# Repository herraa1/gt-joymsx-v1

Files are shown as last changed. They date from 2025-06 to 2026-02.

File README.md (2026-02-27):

# MSX Joystick to Gigatron TTL microcomputer Joystick adapter (gt-joymsx) v1

Connect [MSX Joysticks](https://www.msx.org/wiki/Joystick/joypad_controller) to the [Gigatron TTL microcomputer](https://gigatron.io/).

> [!NOTE]
>
> No build instructions are yet provided, but if you are brave enough go for the [recommended build](#recommended-build).
>

## Introduction

The gt-joymsx v1 is an adapter that allows connecting MSX joysticks to the Gigatron TTL microcomputer.

The main features of the gt-joymsx v1 adapter are:
* small footprint
* made of widely available electronic components
* behaves as a cord extension between the Gigatron TTL microcomputer and the MSX joystick
* uses an extension cable with a female DE9 connector on the adapter's Gigatron TTL microcomputer joystick side
* uses a male DE9 PCB connector on the adapter's MSX joystick side
* no need for external power supply, the adapter draws current from the Gigatron TTL microcomputer joystick port
* super low power consumption

## [Hardware](hardware/kicad/)

The Gigatron TTL microcomputer uses [9-pin Famiclone compatible joysticks](https://www.nesdev.org/wiki/Controller_port_pinout). Those joysticks use a [Texas Instruments 4021 or compatible](https://www.ti.com/lit/ds/symlink/cd4021b.pdf) to latch and serialize the information about the pressed joystick buttons and arrows.

The [standard MSX joysticks](https://www.msx.org/wiki/Joystick/joypad_controller) are completely passive and have parallel signals for each of the buttons and arrows. The MSX computers pull up by default the signals when a MSX joystick is connected, and the MSX joysticks pull the signals to the OUT signal (pin8) when buttons or arrows are pressed (see page 27 of [MSX Technical Data Book](https://map.grauw.nl/resources/system/msxtech.pdf) for a schematic).

The gt-joymsx v1 adapter uses a CD4021BM integrated circuit to convert the signals from the MSX joystick buttons and arrows to the 9-pin Famiclone expected signalling.
As the MSX joysticks lack the `SELECT` and `START`buttons of the Famiclone joysticks, the gt-joymsx v1 adapter itself also provides two Cherry-compatible key switches to add those two buttons.

A two-sided printed circuit board (PCB) is used to put together all components:
* An angled Sega DE9 PCB male connector is used to directly connect the MSX joystick
* A PH2.0 connector is used to connect the Gigatron TTL microcomputer joystick cable extension
* Two Cherry-compatible key switches to implement the `SELECT` and `START` buttons
* the CD4021BM CMOS 8-Stage Static Shift Register
* A pair of pull-up resistor networks to provide default signals for buttons and arrows

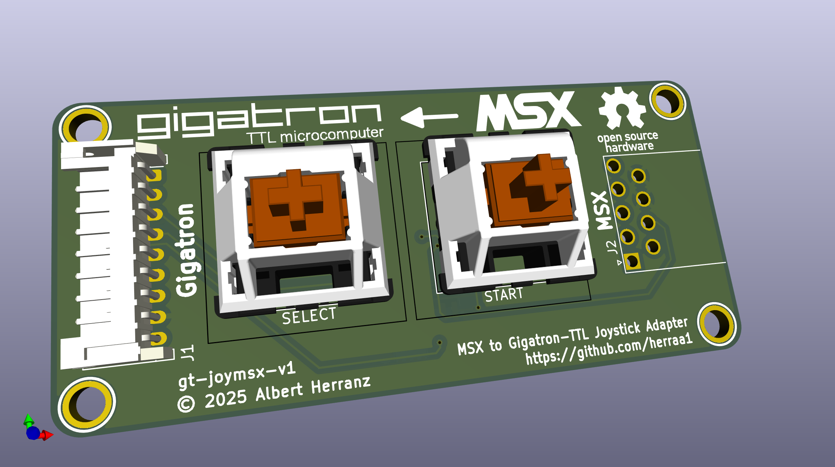
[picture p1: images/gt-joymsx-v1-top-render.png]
[](images/gt-joymsx-v1-top-render.png)

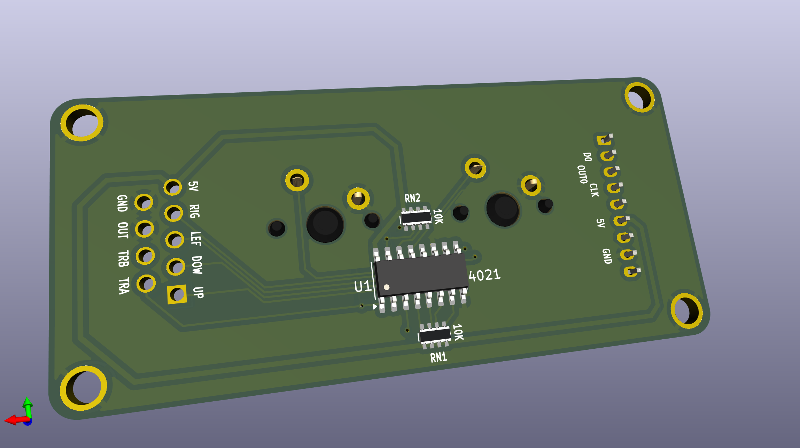
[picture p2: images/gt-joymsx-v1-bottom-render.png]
[](images/gt-joymsx-v1-bottom-render.png)

Connection to the Gigatron TTL microcomputer joystick port is implemented using a DE9 joystick extension cable with a female DE9 connector on one side and a loose end on the other side.
The joystick extension cable loose end is wired according to the following pinout mapping.

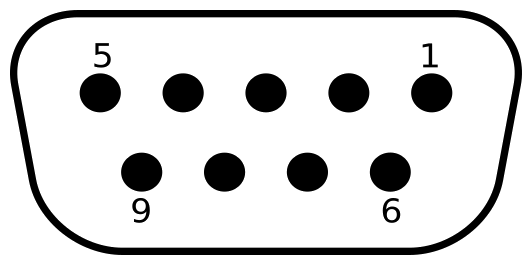
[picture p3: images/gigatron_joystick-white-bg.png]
| [](images/gigatron_joystick-white-bg.png) |
|:--|
| Gigatron TTL microcomputer joystick connector pinout, from adapter extension cable plug side |

| Gigatron side pin | Cable color (may vary) | Signal |
| --- | --- | --- |
| 1 | Red | unconnected |
| 2 | Black | SER_DATA/D0 |
| 3 | Grey | SER_LATCH/OUT0 |
| 4 | Orange | SER_PULSE/CLK  |
| 5 | Brown | unconnected |
| 6 | Green | +5V |
| 7 | White | unconnected |
| 8 | Blue | GND |
| 9 | Yellow | unconnected |

| MSX side pin | Signal |
| --- | --- |
| 1 | UP |
| 2 | DOWN |
| 3 | LEFT |
| 4 | RIGHT  |
| 5 | +5v |
| 6 | TRIGA  |
| 7 | TRIGB  |
| 8 | GND |
| 9 | GND |

### Recommended Build

Please, use [gt-joymsx-v1 Build1](#build1) for making boards.

### [Build1](hardware/kicad/gt-joymsx-v1-build1)

[Bill Of Materials (BoM)](https://htmlpreview.github.io/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)

This board has been successfully built and works fine.

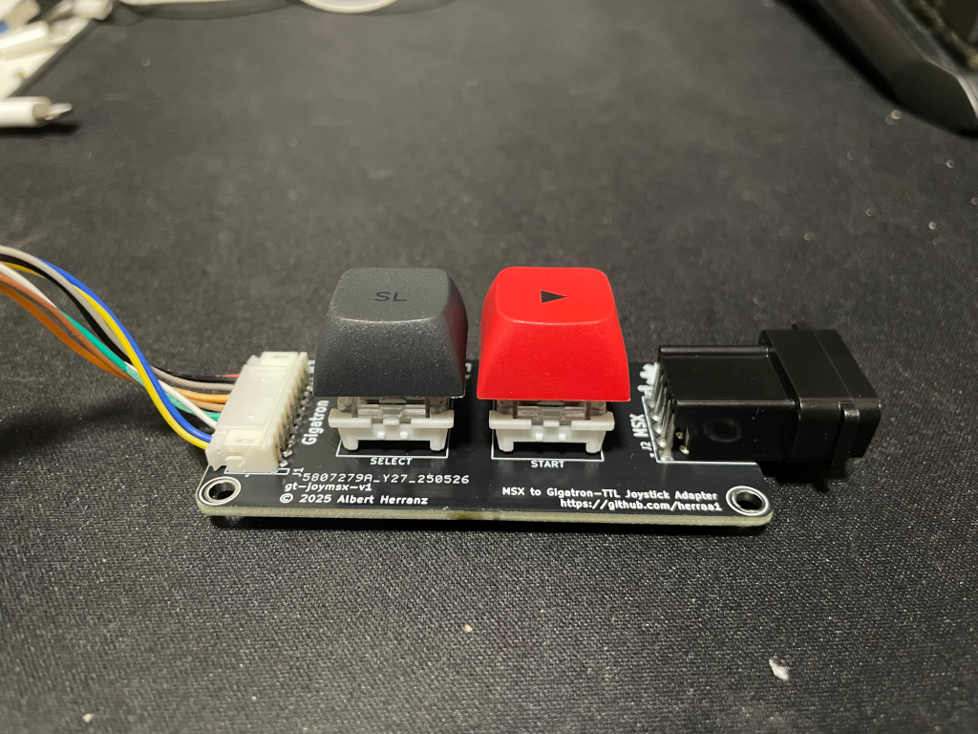
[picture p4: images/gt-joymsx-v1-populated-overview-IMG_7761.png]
[](images/gt-joymsx-v1-populated-overview-IMG_7761.png)

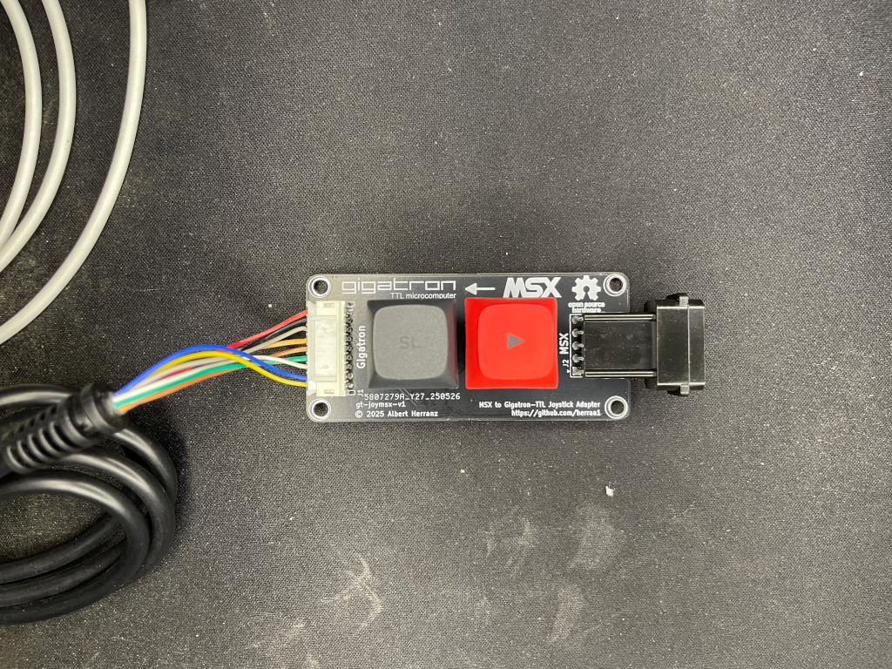
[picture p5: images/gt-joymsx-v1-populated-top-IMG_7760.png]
[](images/gt-joymsx-v1-populated-top-IMG_7760.png)

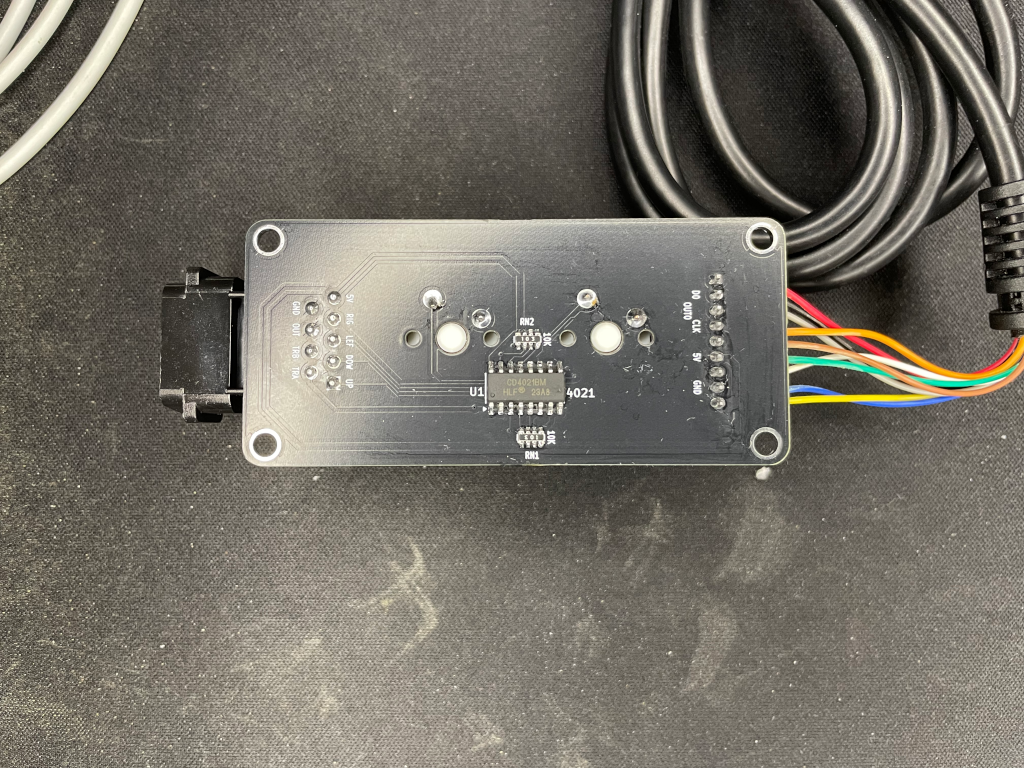
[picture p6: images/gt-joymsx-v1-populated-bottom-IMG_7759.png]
[](images/gt-joymsx-v1-populated-bottom-IMG_7759.png)

## [Enclosure](enclosure/)

A simple acrylic enclosure design for the project is provided to protect the electronic components and provide strain relief for the extension cord.

The enclosure uses a 5mm acrylic sheet.

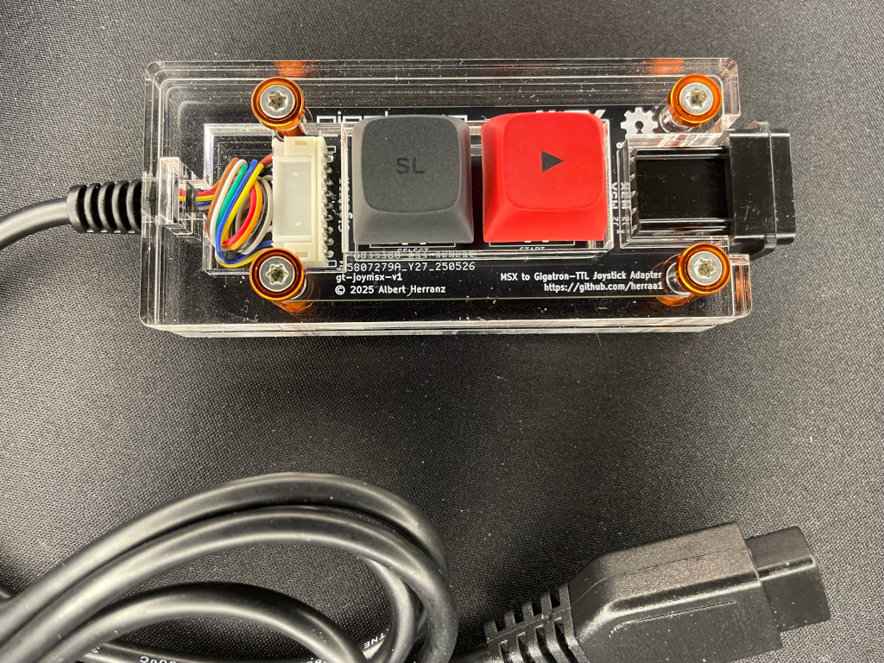
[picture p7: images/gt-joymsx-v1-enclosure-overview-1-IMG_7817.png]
[](images/gt-joymsx-v1-enclosure-overview-1-IMG_7817.png)

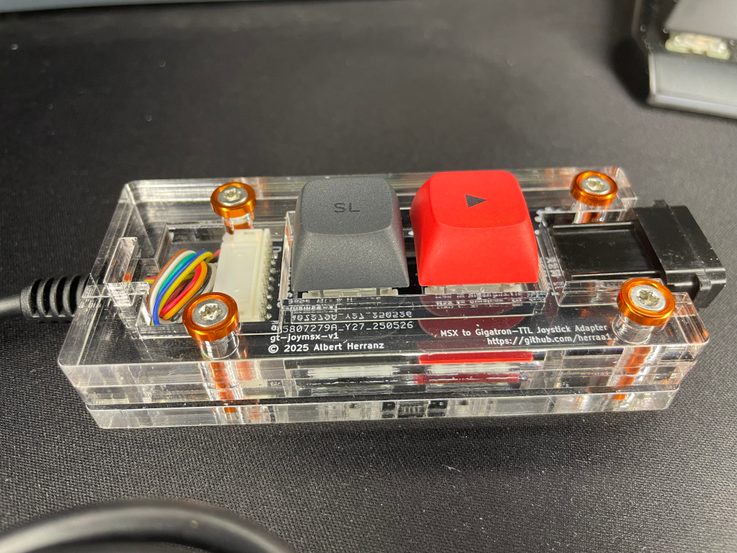
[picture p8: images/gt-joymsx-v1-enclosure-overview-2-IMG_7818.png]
[](images/gt-joymsx-v1-enclosure-overview-2-IMG_7818.png)

## Tips

* By using this adapter in combination with a [msx-joyblue](https://github.com/herraa1/msx-joyblue-v2) adapter you can play games on the Gigatron TTL microcomputer using bluetooth adapters (for example, you can play _Racer_ using a Nintendo Wii Remote with a Wheel)

## References

Gigatron TTL microcomputer
- https://gigatron.io

MSX general purpose I/O port
* https://www.msx.org/wiki/General_Purpose_port

Famiclone pinout
- https://www.nesdev.org/wiki/Controller_port_pinout

4021 pinout
* https://www.nesdev.org/wiki/4021

## Image Sources

* https://www.oshwa.org/open-source-hardware-logo/
* https://en.wikipedia.org/wiki/File:Numbered_DE9_Diagram.svg

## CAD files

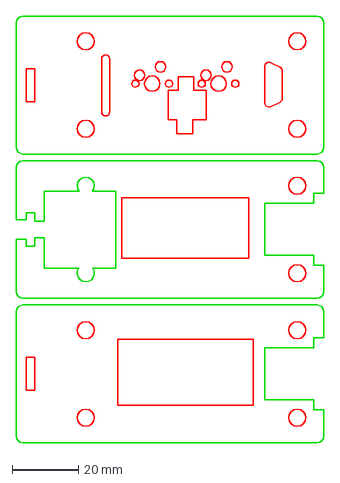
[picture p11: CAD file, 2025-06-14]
enclosure/gt-joymsx-v1-enclosure-dina5-5mm-ready-to-lasercut.dxf
93.0 x 129.1 mm

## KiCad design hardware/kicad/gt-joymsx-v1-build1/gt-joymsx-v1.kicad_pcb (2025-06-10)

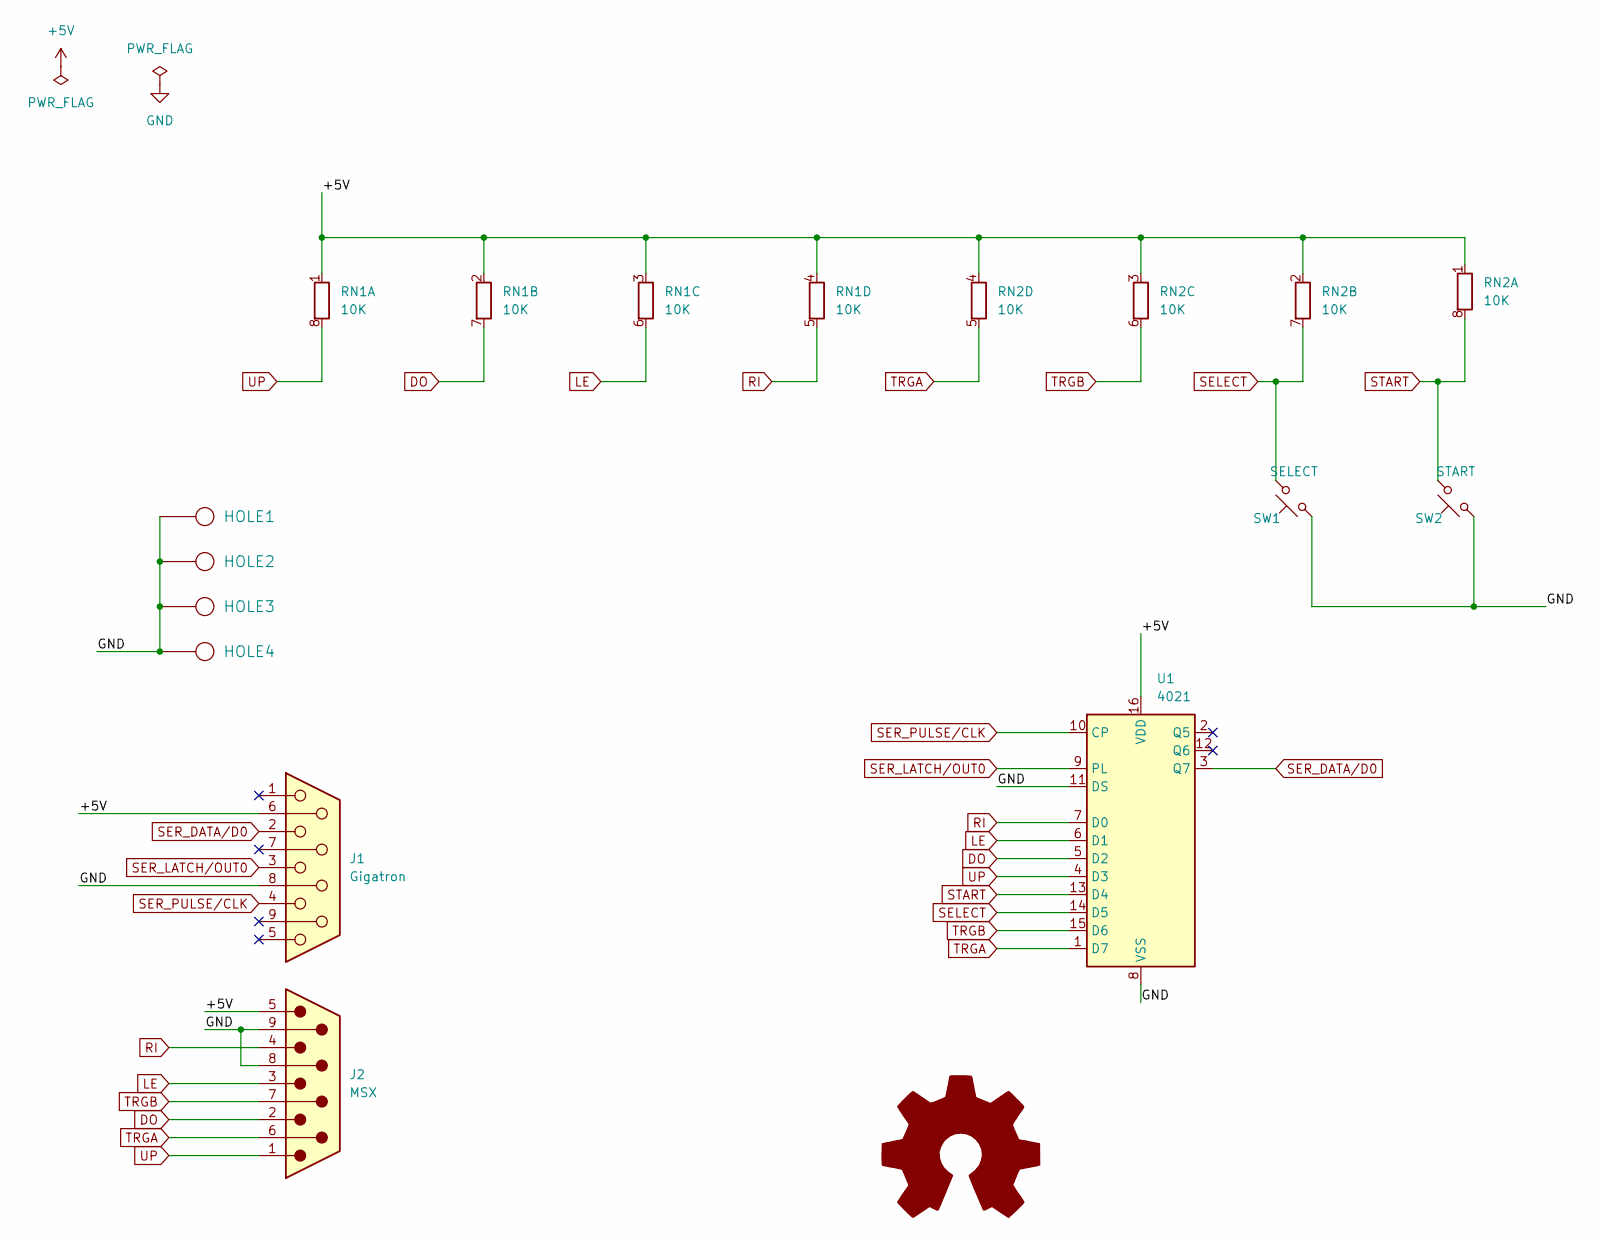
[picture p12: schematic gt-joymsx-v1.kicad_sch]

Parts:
HOLE1, HOLE2, HOLE3, HOLE4: HOLE; Hole_3mm
J1: Gigatron; JST_PH_S9B-PH-K_1x09_P2.00mm_Horizontal
J2: MSX; Sega-DE9_Male_Horizontal_P2.77x2.84mm_EdgePinOffset9.40mm
RN1, RN2: 10K; R_Array_Concave_4x0603
SW1: SELECT; SW_Cherry_MX_PCB_1.00u
SW2: START; SW_Cherry_MX_PCB_1.00u
SYM1: Logo_Open_Hardware_Large; OSHW-Logo_7.5x8mm_SilkScreen
U1: 4021; SOIC-16_3.9x9.9mm_P1.27mm

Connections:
+5V: J1.6, J2.5, RN1.1 (R1.1), RN1.2 (R2.1), RN1.3 (R3.1), RN1.4 (R4.1), RN2.1 (R1.1), RN2.2 (R2.1), RN2.3 (R3.1), RN2.4 (R4.1), U1.16 (VDD)
DO: J2.2, RN1.7 (R2.2), U1.5 (D2)
GND: HOLE1.1, HOLE2.1, HOLE3.1, HOLE4.1, J1.8, J2.8, J2.9, SW1.1, SW2.1, U1.8 (VSS), U1.11 (DS)
LE: J2.3, RN1.6 (R3.2), U1.6 (D1)
RI: J2.4, RN1.5 (R4.2), U1.7 (D0)
SELECT: RN2.7 (R2.2), SW1.2, U1.14 (D5)
SER_DATA/D0: J1.2, U1.3 (Q7)
SER_LATCH/OUT0: J1.3, U1.9 (PL)
SER_PULSE/CLK: J1.4, U1.10 (CP)
START: RN2.8 (R1.2), SW2.2, U1.13 (D4)
TRGA: J2.6, RN2.5 (R4.2), U1.1 (D7)
TRGB: J2.7, RN2.6 (R3.2), U1.15 (D6)
UP: J2.1, RN1.8 (R1.2), U1.4 (D3)

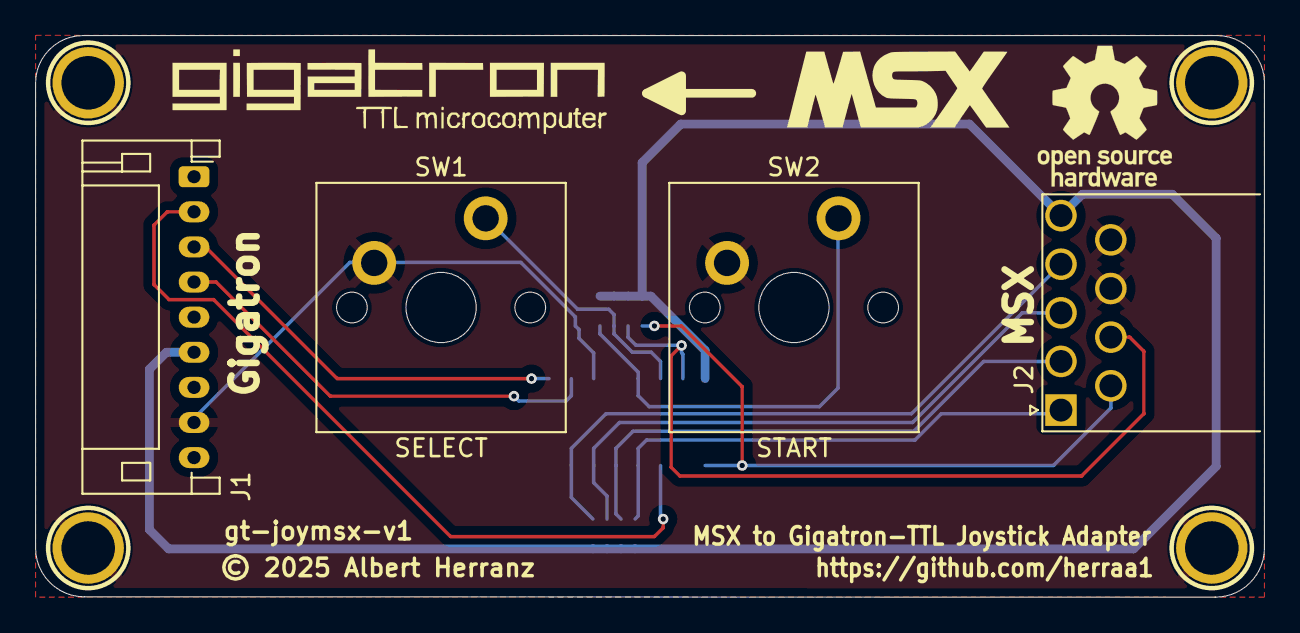
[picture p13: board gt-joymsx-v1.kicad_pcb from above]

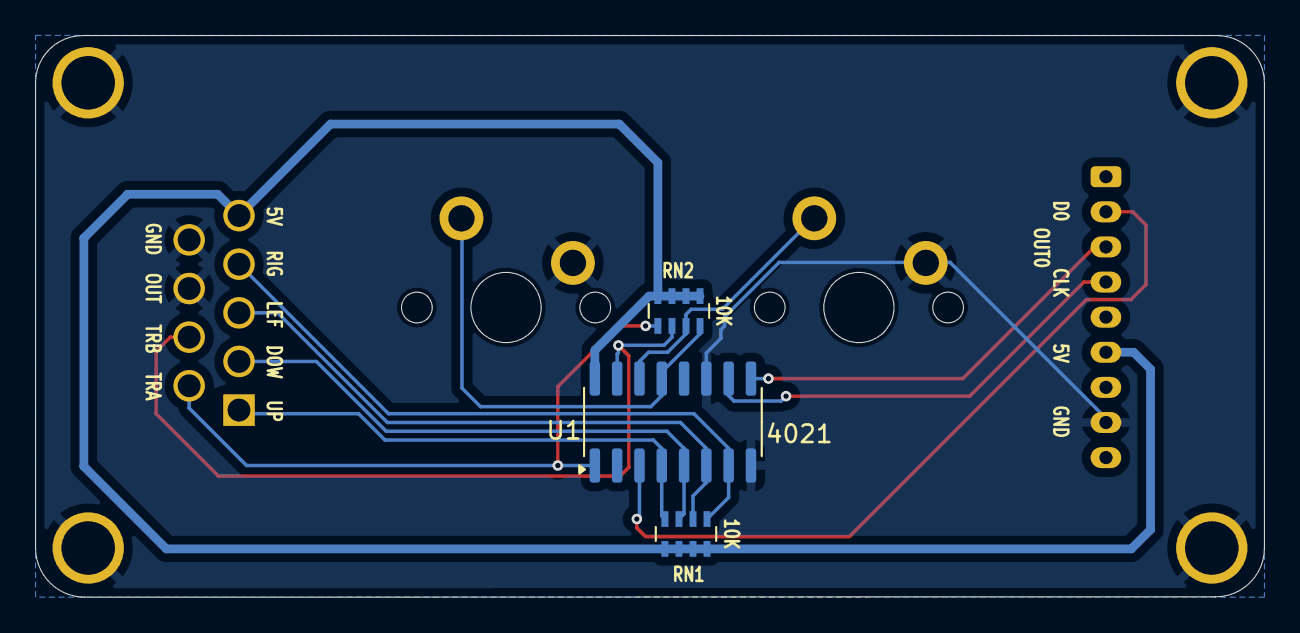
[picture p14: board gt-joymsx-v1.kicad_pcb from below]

Board: 2 copper layers, 70.0 x 32.0 mm, 12 parts (3 on the bottom side), 13 nets.

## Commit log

2025-06-10 Initial commit.
    [gt-joymsx-v1.kicad_pcb, gt-joymsx-v1.kicad_sch]
2025-06-14 enclosure: initial version
    [gt-joymsx-v1-enclosure-dina5-5mm-ready-to-lasercut.dxf]

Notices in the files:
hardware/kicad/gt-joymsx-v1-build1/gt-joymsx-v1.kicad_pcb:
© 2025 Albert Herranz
